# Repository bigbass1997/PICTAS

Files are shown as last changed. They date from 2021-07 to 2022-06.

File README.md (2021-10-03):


### Description
The PICTAS is an input device used to replay Tool-Assisted-Speedruns (aka Tool-Assisted-Superruns) on physical hardware.

A PIC18F47K42 microcontroller is used for the replay portion of the device, and the smaller PIC18F27K42 is used for controlling the input displays.

Unlike a typical TAS replay device, this one stores the TAS inputs on-board, using serial flash memory (W25Q128JVSIQ), capable of storing 16 MB of input data. The advantage is that USB communication is not required during replay. It simplifies the replay process, and greatly reduces the chance of corrupted inputs. Additionally, once programmed, the device can be used without a USB host computer (WIP feature).

This project is still a prototype under heavy development. While I will offer help and support as best I can, please understand that significant code and design changes can occur at any time.

### Usage
The general process looks like this: Load movie into a [host interface](https://github.com/bigbass1997/pictas-interface-rs). Program the movie's inputs and config options onto the PICTAS device. Finally, use one of the available start methods to begin the playback.

Refer to the [PICTAS-Interface project](https://github.com/bigbass1997/pictas-interface-rs) for details on how to use that software. Anyone is free to make their own interface software. There will be docs provided here once the communication protocol has stablized. The PICTAS communicates over USB at a 500,000 baud rate. Single byte commands are initiated from the interface. The PICTAS will respond with one or more bytes.

Because the input data is saved onto the device, you will _not_ need to reprogram it again unless you wish to change the TAS inputs or other configuration data.

### Flash Memory Map
```
0x000000 - 0xFFEFFF | Sequential controller inputs
0xFFF000 - 0xFFF0FF | Config options
0xFFF100 - 0xFFFFFF | Frame-numbered commands
```
All except the last sector (4KB) of memory, is dedicated to storing the TAS inputs. Format will depend on the console and how many controllers are used. Within the last sector, the first 256 bytes are for config options, while the rest is for special commands that are performed on specific frame numbers.

Each command is made up of a 3 byte wide number, which specifies the frame number. And then a 1 byte command.
```
0x00 | Console Reset
0x01 | Console Power off and on

0xFF | Null
```

### Input Displays
This replay device also supports input displays (aka viz/visualization boards), providing the viewers a way see which inputs are being pressed in real time.

The displays are designed to be placed on a SPI bus, where each display board shares the same clock and serial signals. Each device uses it's own Chip Select signal as a data latch.

An auxilary power supply must be connected for these displays. The PCB design is rated for a maximum of 2Amps.

### Discord/Support
If you have questions or suggestions, you can find me on the [N64brew Discord server](https://discord.gg/WqFgNWf) or the [TASBot server](https://discord.tas.bot/).

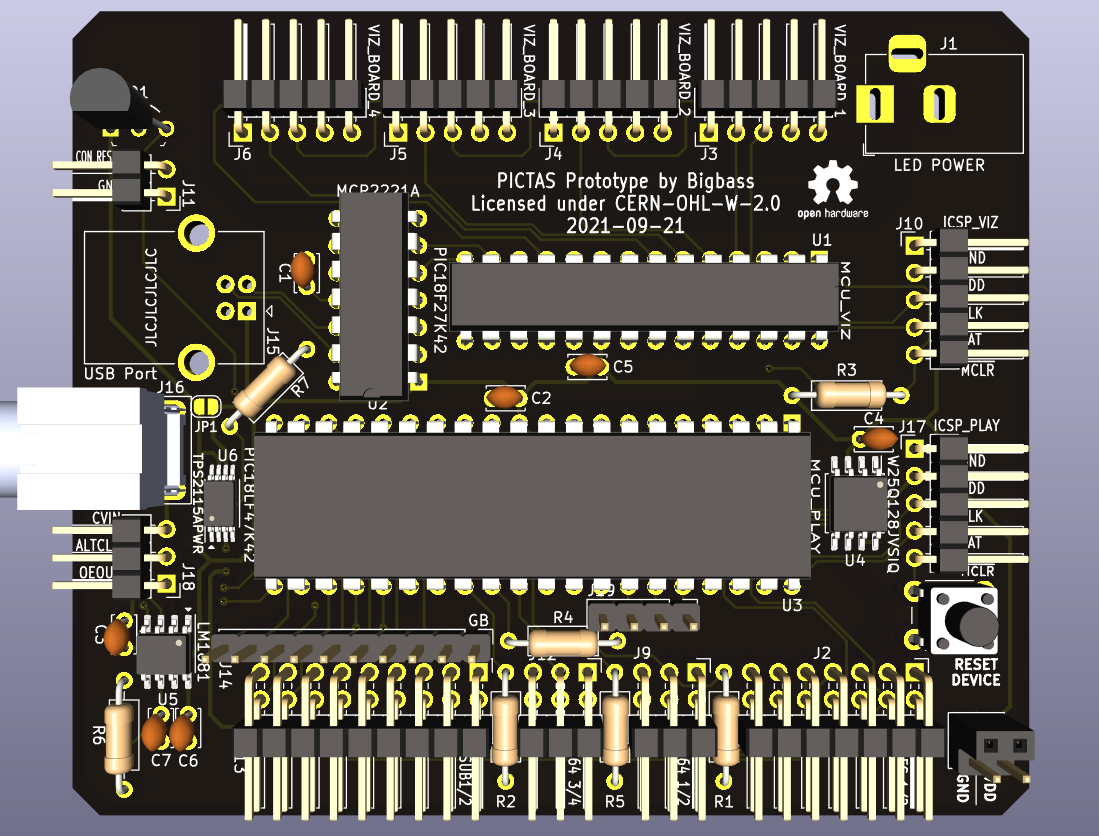
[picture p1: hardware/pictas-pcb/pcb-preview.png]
pcb design


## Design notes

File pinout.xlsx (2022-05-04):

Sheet: MCU-Play
Notes | I/O | Usage | Name | Pin |  | Pin | Name | Usage | I/O | Notes | Color Scheme
 | O | VPP/MCLR | RE3 | 1 | PIC18F47K42 | 40 | RB7 | ICSPDAT | I |  | PORTA
 | I/O | GEN/A2600/NES_LATCH | RA0 | 2 |  | 39 | RB6 | ICSPCLK | I |  | PORTB
 | I/O | GEN/A2600/NES_CLK1 | RA1 | 3 |  | 38 | RB5 | U1TX | O | UART1 TX | PORTC
 | O | GEN/A2600/NES_DATA1 | RA2 | 4 |  | 37 | RB4 | U1RX | I | UART1 RX | PORTD
 | I/O | GEN/A2600/NES_CLK2 | RA3 | 5 |  | 36 | RB3 | SPI1SDO | O | SDO | PORTE
 | O | GEN/A2600/NES_DATA2 | RA4 | 6 |  | 35 | RB2 | SPI1SCK | O | CLK | ICSP
 | O | GEN/A2600 | RA5 | 7 |  | 34 | RB1 | FLASH_CS | O | Flash Select
 |  |  | RE0 | 8 |  | 33 | RB0 | SPI1SDOI | I | SDI
 |  |  | RE1 | 9 |  | 32 | VDD
Write to Host | O | UART_HOST | RE2 | 10 |  | 31 | VSS
 |  |  | VDD | 11 |  | 30 | RD7 | N64_DATA4 | I/O
 |  |  | VSS | 12 |  | 29 | RD6 | N64_DATA3 | I/O
Alternative CLK | I | ALT_CLK | RA7 | 13 |  | 28 | RD5 | N64_DATA2 | I/O
 | O | GEN/A2600 | RA6 | 14 |  | 27 | RD4 | N64_DATA1 | I/O
 | O | GB/GEN/A2600 | RC0 | 15 |  | 26 | RC7 | GB | O
 | O | GB/GEN/A2600 | RC1 | 16 |  | 25 | RC6 | GB/GEN/A2600 | O
 | O | GB/GEN/A2600 | RC2 | 17 |  | 24 | RC5 | GB/GEN/A2600 | O
 | O | GB/GEN/A2600 | RC3 | 18 |  | 23 | RC4 | GB/GEN/A2600 | O
 |  |  | RD0 | 19 |  | 22 | RD3
Reset Console | O | CON_RESET | RD1 | 20 |  | 21 | RD2 | OEOUT | I | Odd/Even Field

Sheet: MCU-Viz
Notes | I/O | Usage | Name | Pin |  | Pin | Name | Usage | I/O | Notes | Color Scheme
 | O | VPP/MCLR | RE3 | 1 | PIC18F27K42 | 28 | RB7 | ICSPDAT | O |  | PORTA
 |  |  | RA0 | 2 |  | 27 | RB6 | ICSPCLK | O |  | PORTB
 |  |  | RA1 | 3 |  | 26 | RB5 | U2RX | I | UART-->MCU_PLAY | PORTC
 | O | STROBE1 | RA2 | 4 |  | 25 | RB4 | U2TX | O | UART<--MCU_PLAY | ICSP
 | O | STROBE2 | RA3 | 5 |  | 24 | RB3 | UART_HOST | I | Write to Host
 | O | STROBE3 | RA4 | 6 |  | 23 | RB2
 | O | STROBE4 | RA5 | 7 |  | 22 | RB1
 |  |  | VSS | 8 |  | 21 | RB0
 |  |  | RA7 | 9 |  | 20 | VDD
 |  |  | RA6 | 10 |  | 19 | VSS
SER | O | SPI1SDO | RC0 | 11 |  | 18 | RC7
CLK | O | SPI1SCK | RC1 | 12 |  | 17 | RC6
USB-->UART | I | U1RX | RC2 | 13 |  | 16 | RC5
USB<--UART | O | U1TX | RC3 | 14 |  | 15 | RC4

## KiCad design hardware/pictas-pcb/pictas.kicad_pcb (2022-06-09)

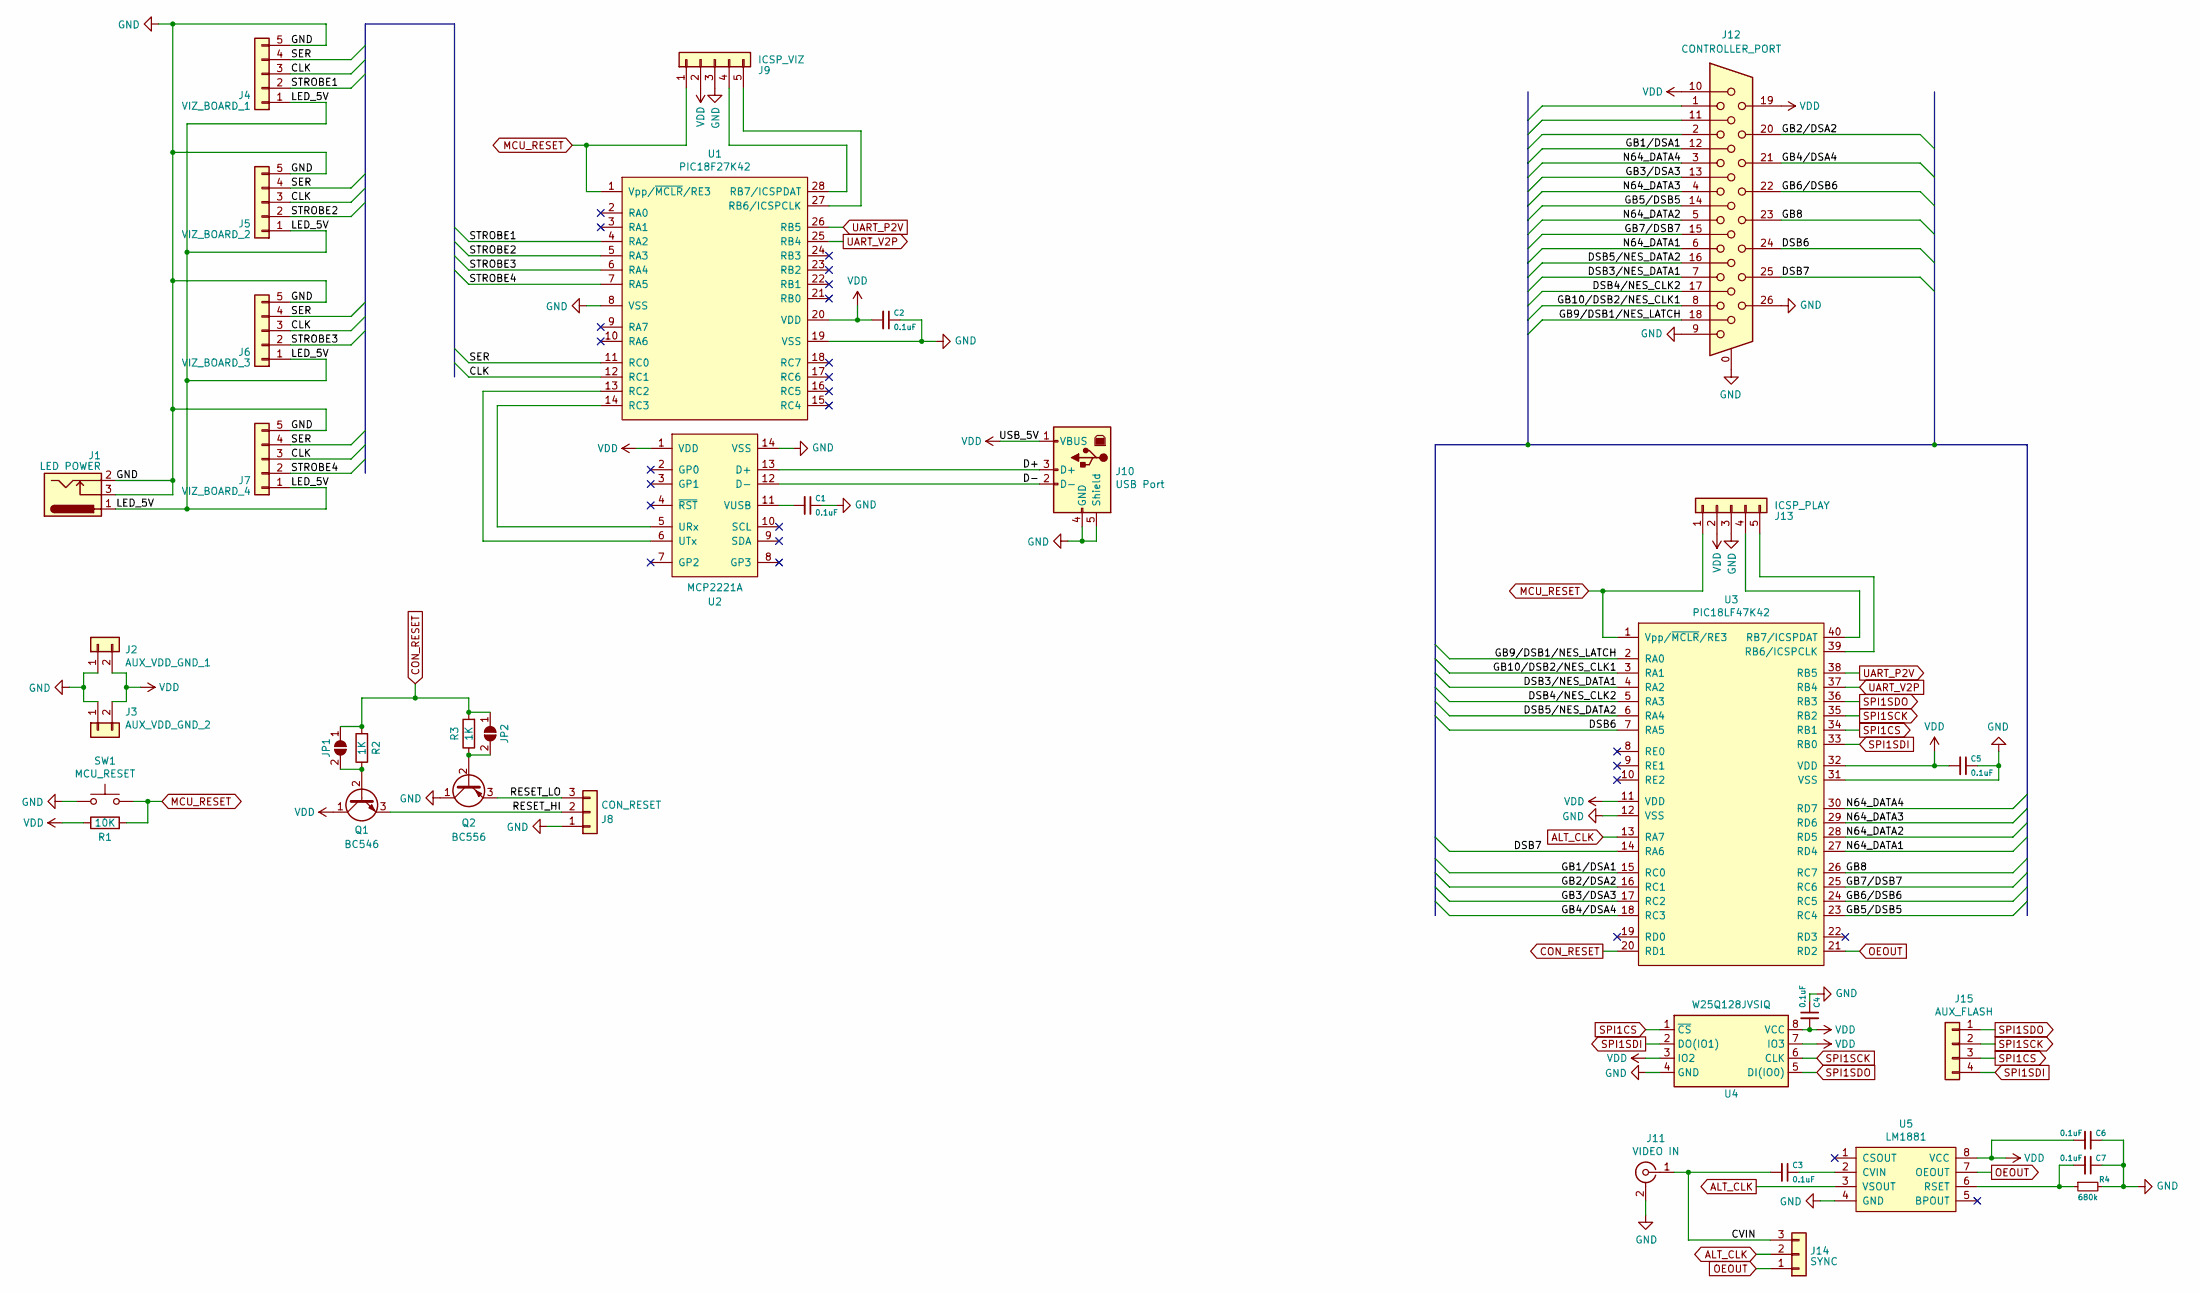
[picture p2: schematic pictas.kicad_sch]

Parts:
C1, C2, C3, C4, C5, C6, C7: 0.1uF; C_Disc_D3.4mm_W2.1mm_P2.50mm
J1: LED POWER; BarrelJack_Horizontal
J2: AUX_VDD_GND_1; PinHeader_1x02_P2.54mm_Vertical
J3: AUX_VDD_GND_2; PinSocket_1x02_P2.54mm_Vertical
J4: VIZ_BOARD_1; PinHeader_1x05_P2.54mm_Horizontal
J5: VIZ_BOARD_2; PinHeader_1x05_P2.54mm_Horizontal
J6: VIZ_BOARD_3; PinHeader_1x05_P2.54mm_Horizontal
J7: VIZ_BOARD_4; PinHeader_1x05_P2.54mm_Horizontal
J8: CON_RESET; PinHeader_1x03_P2.54mm_Horizontal
J9: ICSP_VIZ; PinSocket_1x05_P2.54mm_Horizontal
J10: USB Port; USB_B_OST_USB-B1HSxx_Horizontal
J11: VIDEO IN; PJRAN1X1U04X
J12: CONTROLLER_PORT; L77HDA26SD1CH4R
J13: ICSP_PLAY; PinSocket_1x05_P2.54mm_Horizontal
J14: SYNC; PinHeader_1x03_P2.54mm_Horizontal
J15: AUX_FLASH; PinHeader_1x04_P2.54mm_Vertical
JP1, JP2: SolderJumper_2_Open; SolderJumper-2_P1.3mm_Open_TrianglePad1.0x1.5mm
Q1: BC546; TO-92_Inline
Q2: BC556; TO-92_Inline
R1: 10K; R_Axial_DIN0207_L6.3mm_D2.5mm_P10.16mm_Horizontal
R2, R3: 1K; R_Axial_DIN0207_L6.3mm_D2.5mm_P10.16mm_Horizontal
R4: 680k; R_Axial_DIN0207_L6.3mm_D2.5mm_P10.16mm_Horizontal
SW1: MCU_RESET; SW_PUSH_6mm_H7.3mm
U1: PIC18F27K42; DIP-28_W7.62mm
U2: MCP2221A; DIP-14_W7.62mm
U3: PIC18LF47K42; DIP-40_W15.24mm
U4: W25Q128JVSIQ; SOIC-8_5.275x5.275mm_P1.27mm
U5: LM1881; SOIC-8_3.9x4.9mm_P1.27mm

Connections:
/CLK: J4.3, J5.3, J6.3, J7.3, U1.12 (RC1)
/CVIN: C3.2, J11.1 (In), J14.3
/D+: J10.3 (D+), U2.13 (D+)
/D-: J10.2 (D-), U2.12 (D-)
/DSB3/NES_DATA1: J12.7, U3.4 (RA2)
/DSB4/NES_CLK2: J12.17, U3.5 (RA3)
/DSB5/NES_DATA2: J12.16, U3.6 (RA4)
/DSB6: J12.24, U3.7 (RA5)
/DSB7: J12.25, U3.14 (RA6)
/GB1/DSA1: J12.12, U3.15 (RC0)
/GB2/DSA2: J12.20, U3.16 (RC1)
/GB3/DSA3: J12.13, U3.17 (RC2)
/GB4/DSA4: J12.21, U3.18 (RC3)
/GB5/DSB5: J12.14, U3.23 (RC4)
/GB6/DSB6: J12.22, U3.24 (RC5)
/GB7/DSB7: J12.15, U3.25 (RC6)
/GB8: J12.23, U3.26 (RC7)
/GB9/DSB1/NES_LATCH: J12.18, U3.2 (RA0)
/GB10/DSB2/NES_CLK1: J12.8, U3.3 (RA1)
/LED_5V: J1.1, J4.1, J5.1, J6.1, J7.1
/N64_DATA1: J12.6, U3.27 (RD4)
/N64_DATA2: J12.5, U3.28 (RD5)
/N64_DATA3: J12.4, U3.29 (RD6)
/N64_DATA4: J12.3, U3.30 (RD7)
/RESET_HI: J8.2, Q1.3 (E)
/RESET_LO: J8.3, Q2.3 (E)
/SER: J4.4, J5.4, J6.4, J7.4, U1.11 (RC0)
/STROBE1: J4.2, U1.4 (RA2)
/STROBE2: J5.2, U1.5 (RA3)
/STROBE3: J6.2, U1.6 (RA4)
/STROBE4: J7.2, U1.7 (RA5)
ALT_CLK: J14.2, U3.13 (RA7), U5.3 (VSOUT)
CON_RESET: JP1.1 (A), JP2.1 (A), R2.2, R3.2, U3.20 (RD1)
GND: C1.1, C2.1, C4.1, C5.1, C6.1, C7.1, J1.2, J1.3, J2.1, J3.1, J4.5, J5.5, J6.5, J7.5, J8.1, J9.3, J10.4 (GND), J10.5 (Shield), J11.2 (Ext), J12.0, J12.9, J12.26, J13.3, Q2.1 (C), R4.2, SW1.1, U1.8 (VSS), U1.19 (VSS), U2.14 (VSS), U3.12 (VSS), U3.31 (VSS), U4.4 (GND), U5.4 (GND)
MCU_RESET: J9.1, J13.1, R1.2, SW1.2, U1.1 (Vpp/~MCLR/RE3), U3.1 (Vpp/~MCLR/RE3)
unnamed: C1.2, U2.11 (VUSB)
unnamed: C3.1, U5.2 (CVIN)
unnamed: C7.2, R4.1, U5.6 (RSET)
unnamed: J9.4, U1.28 (RB7/ICSPDAT)
unnamed: J9.5, U1.27 (RB6/ICSPCLK)
unnamed: J13.4, U3.40 (RB7/ICSPDAT)
unnamed: J13.5, U3.39 (RB6/ICSPCLK)
unnamed: JP1.2 (B), Q1.2 (B), R2.1
unnamed: JP2.2 (B), Q2.2 (B), R3.1
unnamed: U1.13 (RC2), U2.6 (UTx)
unnamed: U1.14 (RC3), U2.5 (URx)
OEOUT: J14.1, U3.21 (RD2), U5.7 (OEOUT)
SPI1CS: J15.3, U3.34 (RB1), U4.1 (~CS)
SPI1SCK: J15.2, U3.35 (RB2), U4.6 (CLK)
SPI1SDI: J15.4, U3.33 (RB0), U4.2 (DO(IO1))
SPI1SDO: J15.1, U3.36 (RB3), U4.5 (DI(IO0))
UART_P2V: U1.26 (RB5), U3.38 (RB5)
UART_V2P: U1.25 (RB4), U3.37 (RB4)
VDD: C2.2, C4.2, C5.2, C6.2, J2.2, J3.2, J9.2, J10.1 (VBUS), J12.10, J12.19, J13.2, Q1.1 (C), R1.1, U1.20 (VDD), U2.1 (VDD), U3.11 (VDD), U3.32 (VDD), U4.3 (IO2), U4.7 (IO3), U4.8 (VCC), U5.8 (VCC)

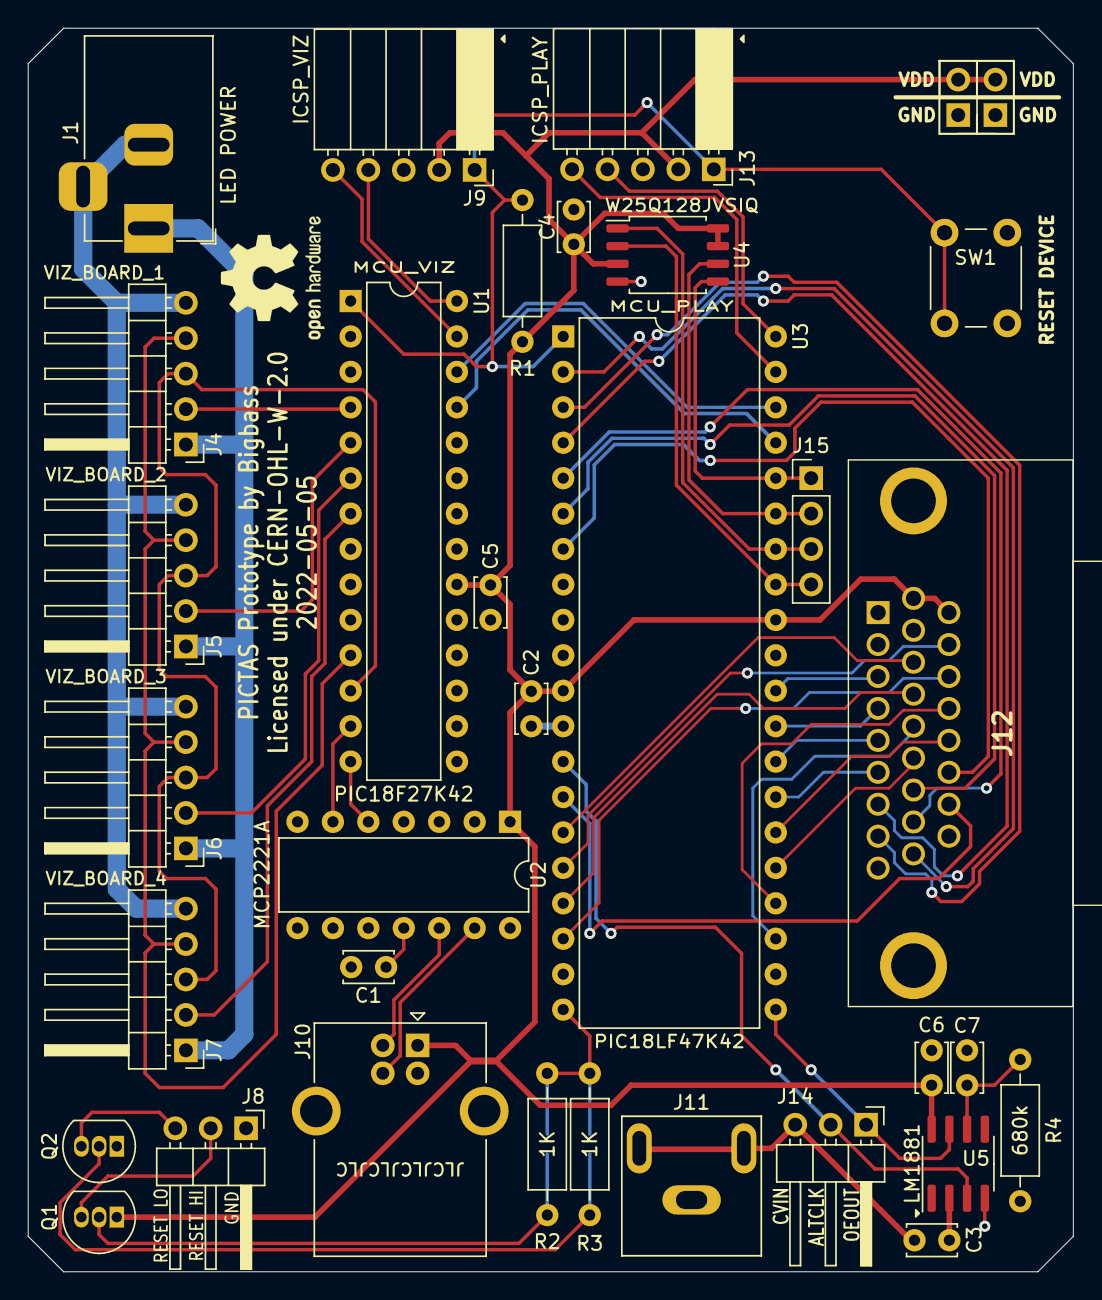
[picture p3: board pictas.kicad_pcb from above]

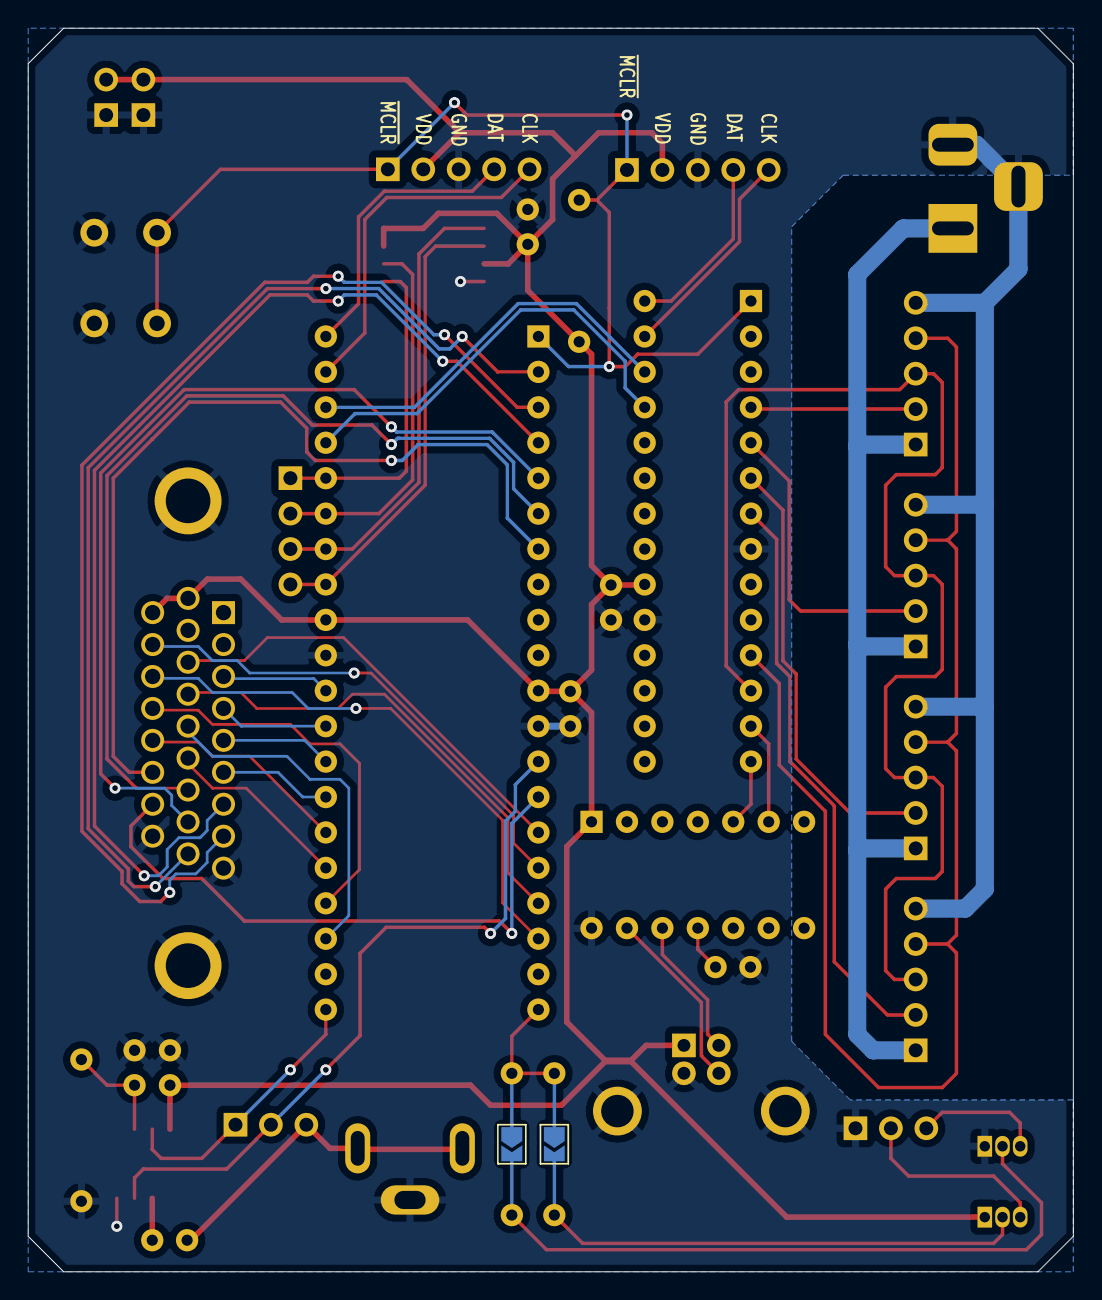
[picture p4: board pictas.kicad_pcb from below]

Board: 2 copper layers, 74.9 x 89.2 mm, 36 parts (2 on the bottom side), 54 nets.

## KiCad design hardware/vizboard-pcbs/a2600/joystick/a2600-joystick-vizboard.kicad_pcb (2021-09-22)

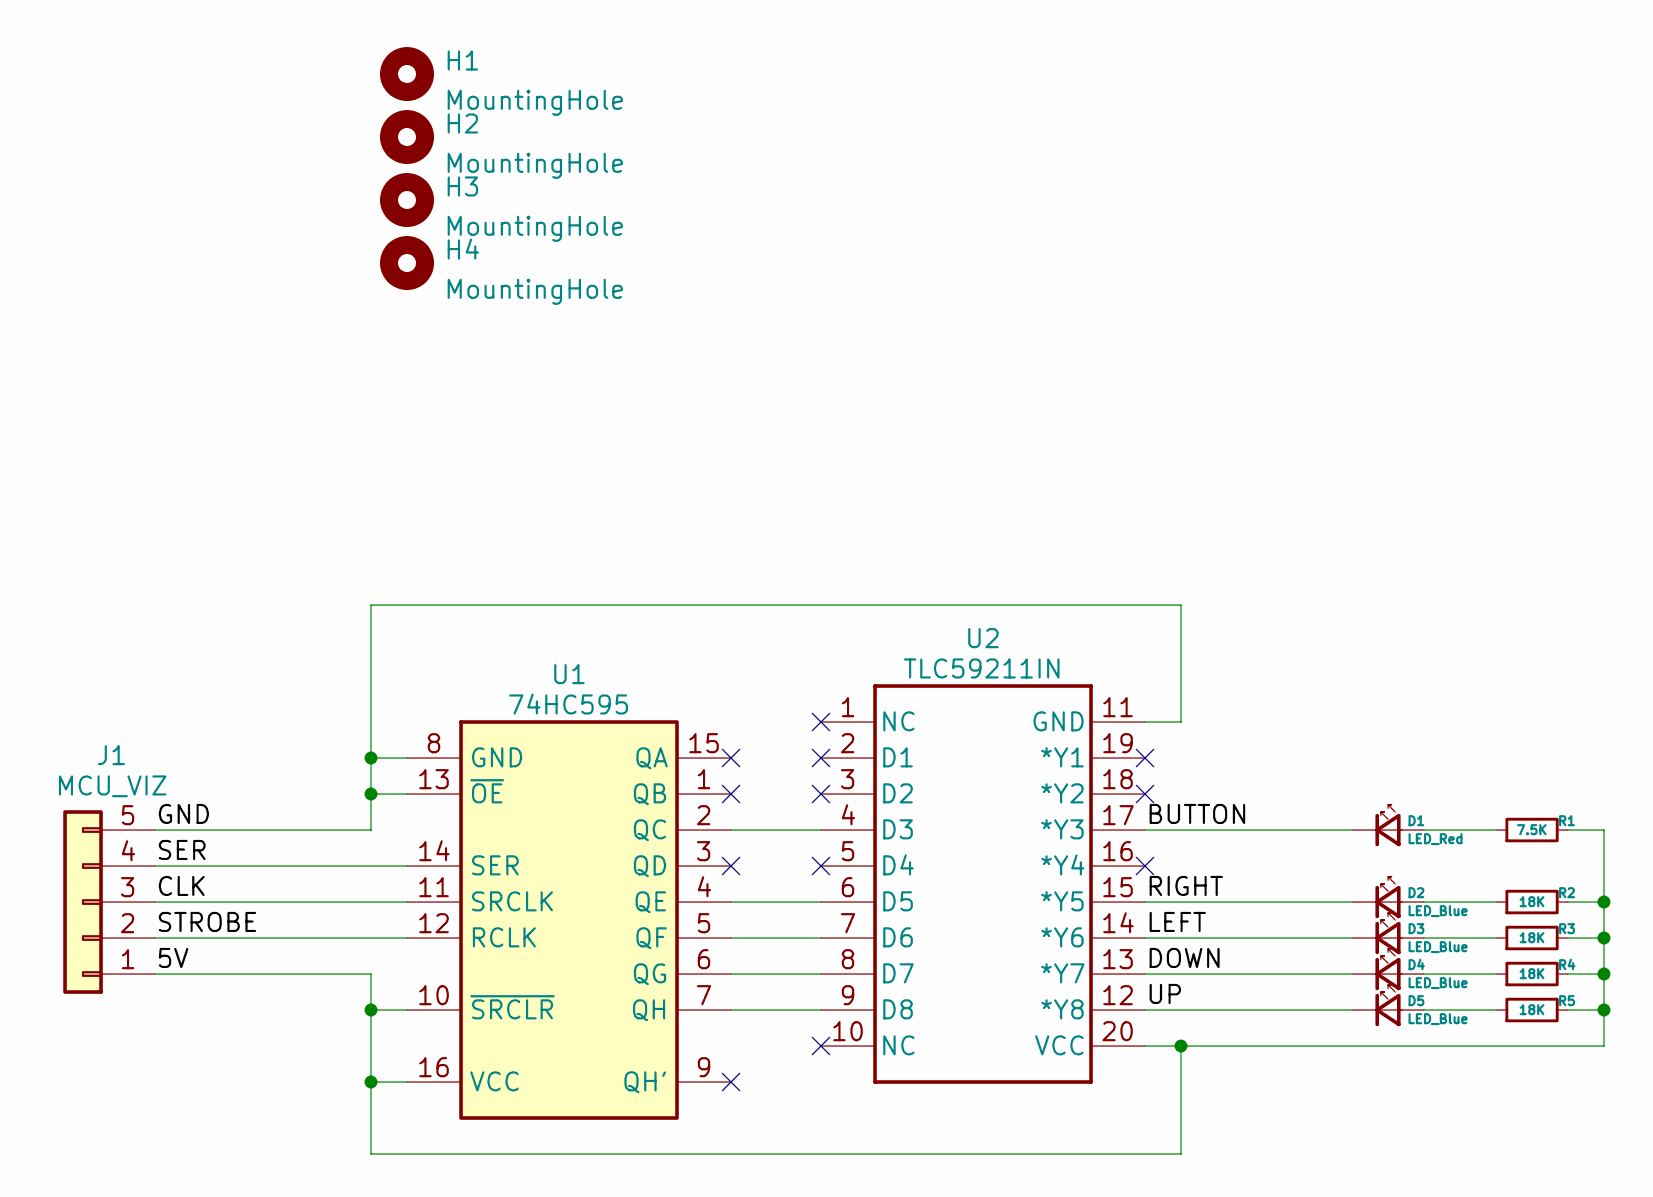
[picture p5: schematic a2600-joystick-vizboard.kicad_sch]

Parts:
D1: LED_Red; LED_D5.0mm
D2, D3, D4, D5: LED_Blue; LED_D5.0mm
H1, H2, H3, H4: MountingHole; MountingHole_3.2mm_M3
J1: MCU_VIZ; PinHeader_1x05_P2.54mm_Horizontal
R1: 7.5K; R_Axial_DIN0207_L6.3mm_D2.5mm_P10.16mm_Horizontal
R2, R3, R4, R5: 18K; R_Axial_DIN0207_L6.3mm_D2.5mm_P10.16mm_Horizontal
U1: 74HC595; DIP-16_W7.62mm
U2: TLC59211IN; DIP-20_W7.62mm

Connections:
/5V: J1.1, R1.2, R2.2, R3.2, R4.2, R5.2, U1.10 (~SRCLR), U1.16 (VCC), U2.20 (VCC)
/BUTTON: D1.1 (K), U2.17 (*Y3)
/CLK: J1.3, U1.11 (SRCLK)
/DOWN: D4.1 (K), U2.13 (*Y7)
/GND: J1.5, U1.8 (GND), U1.13 (~OE), U2.11 (GND)
/LEFT: D3.1 (K), U2.14 (*Y6)
/RIGHT: D2.1 (K), U2.15 (*Y5)
/SER: J1.4, U1.14 (SER)
/STROBE: J1.2, U1.12 (RCLK)
/UP: D5.1 (K), U2.12 (*Y8)
unnamed: D1.2 (A), R1.1
unnamed: D2.2 (A), R2.1
unnamed: D3.2 (A), R3.1
unnamed: D4.2 (A), R4.1
unnamed: D5.2 (A), R5.1
unnamed: U1.2 (QC), U2.4 (D3)
unnamed: U1.4 (QE), U2.6 (D5)
unnamed: U1.5 (QF), U2.7 (D6)
unnamed: U1.6 (QG), U2.8 (D7)
unnamed: U1.7 (QH), U2.9 (D8)

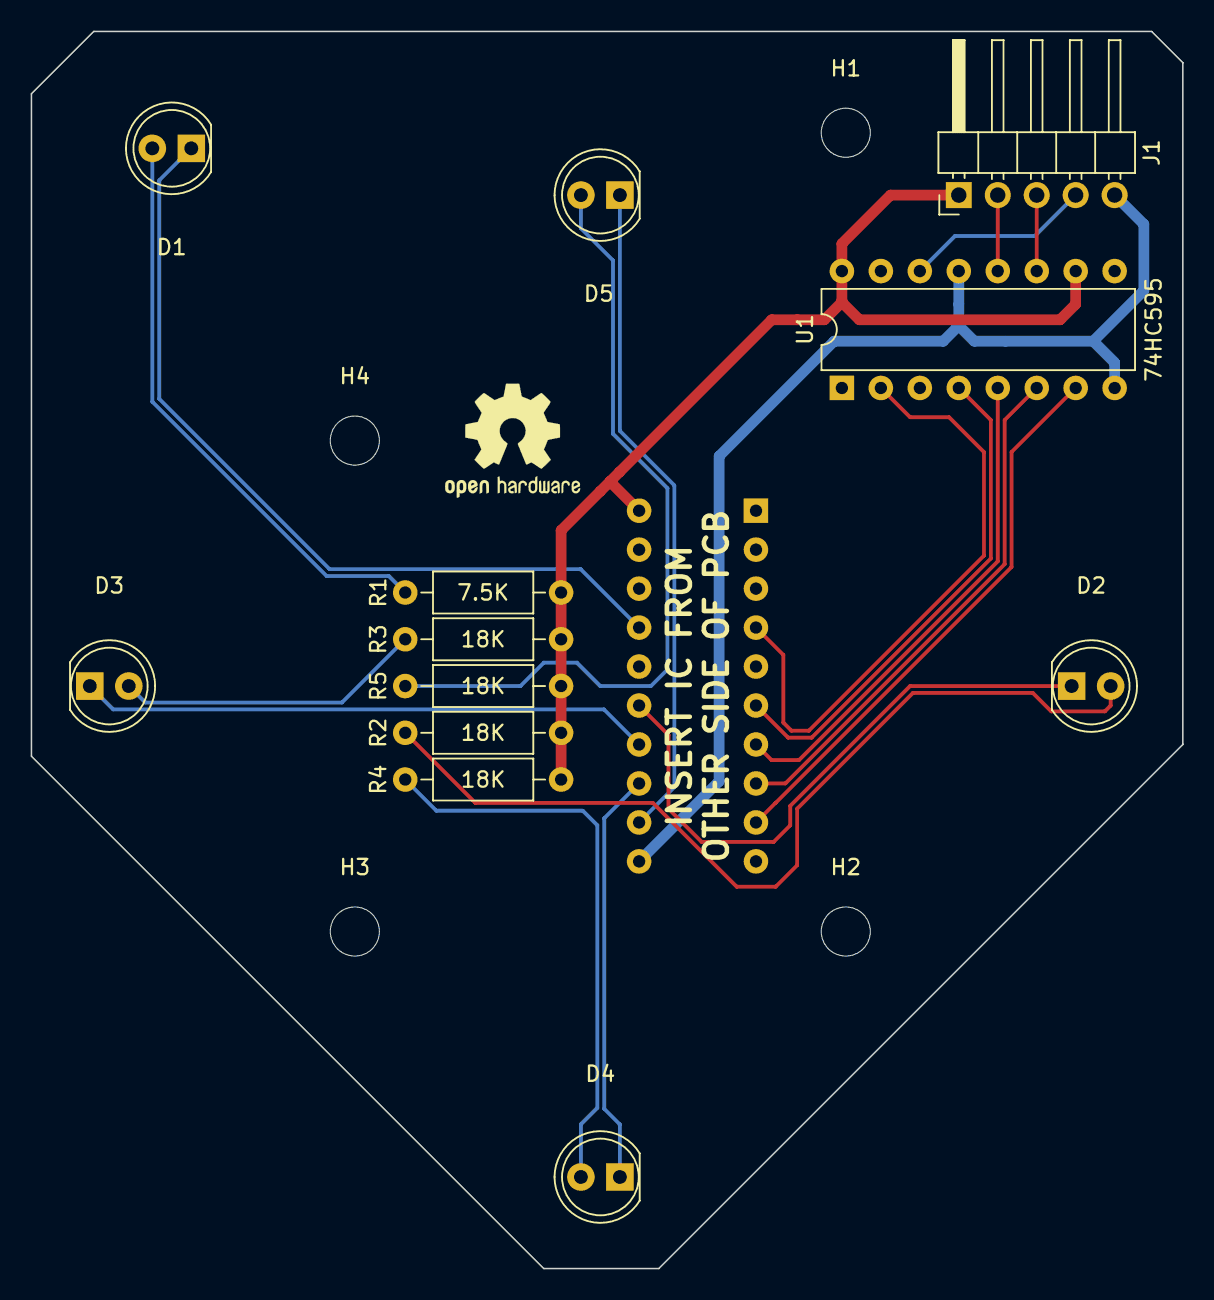
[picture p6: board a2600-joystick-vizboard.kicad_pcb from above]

Board: 2 copper layers, 75.1 x 80.6 mm, 17 parts (1 on the bottom side), 20 nets.

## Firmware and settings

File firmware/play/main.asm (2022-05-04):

    include "p18f47k42.inc"
    include "macros.inc"
    processor 18f47k42
    
    CONFIG WDTE = OFF
   ; CONFIG DEBUG = ON
    CONFIG LVP = ON
    CONFIG MCLRE = EXTMCLR
    CONFIG MVECEN = ON ; Eanbles Interrupt Vector Table ; IVTBASE + 2*(vector number)
    
    CONFIG RSTOSC = HFINTOSC_64MHZ
    CONFIG FEXTOSC = OFF
    CONFIG CLKOUTEN = OFF
    
    CONFIG XINST = ON
    
ResVec      code	0x0000
    goto    Setup
    
IOCVec	    code	0x0016	; (0x0008 + (2 * 7))
    dw	    (0x0100>>2)
    
INT0Vec	    code	0x0018	; (0x0008 + (2 * 8))
    dw	    (0x0300>>2)
    
TMR0Vec	    code	0x0046	; (0x0008 + (2 * 31))
    dw	    (0x0500>>2)
    
U1RXVec	    code	0x003E	; (0x0008 + (2 * 27))
    dw	    (0x0600>>2)
    
	    code	0x1000
; === Look at bottom of file for ISR routines ===
    
; === DEFINE PINS (text substitutions) ===
; refer to pinout documentation for more information
; reminder: all button input pins should be pulled-DOWN (default state is cleared aka 0)
;           connect pin to power to set button to a "pressed" state
#define	    PIN_NES_DATA2	LATA,  4
#define	    PIN_NES_CLK2	PORTA, 3

#define	    PIN_NES_DATA1	LATA,  2
#define	    PIN_NES_CLK1	PORTA, 1

#define	    PIN_NES_LATCH	PORTA, 0    ; Latch pins for each controller are connected at console-level

#define     PIN_FLASH_CS        LATB,  1
#define	    PIN_FLASH_CS_RD	PORTB, 1    ; Used to check what the last set state was

#define	    PIN_UART_HOST	LATE,  2    ; Signal to MCU_Viz whether to write UART to host or not

#define     PIN_N64_DATAIN      PORTD, 4
#define     PIN_N64_DATAOUT     LATD,  4    ; LAT register is used for writing data out
#define     TRIS_N64_DATA       TRISD, 4

#define	    PIN_STAT_LED	LATD,  0    ; Status LED indicator
#define	    PIN_CON_RESET	LATD,  1


; === REGISTERS ===
; ACCESS BANK  (0x00 - 0x5F)
ZEROS_REG       equ H'00' ; Always 0x00
ONES_REG        equ H'01' ; Always 0xFF

N64_BIT_REG     equ H'02' ; This register is used to temporarily store 3-4us of data
                          ; to determine if the data recieved is a 0 or 1 or a stop bit.
N64_CMD_REG     equ H'03'

; 0x04 - 0x07 unused

N64_STATE_REG1  equ H'08' ; Buffer:  Button states
N64_STATE_REG2  equ H'09' ; Buffer:  Button states
N64_STATE_REG3  equ H'0A' ; Buffer:  Analog Stick X-Axis ; -127 to +128
N64_STATE_REG4  equ H'0B' ; Buffer:  Analog Stick Y-Axis ; -127 to +128

TX_DATA         equ H'0C' ; Alias for TX_DATA1
TX_DATA1        equ H'0C' ; Data to be transmitted to the console
TX_DATA2        equ H'0D' ; Data to be transmitted to the console, used as "double buffer"

UTIL_FLAGS      equ H'0E' ; Utility Flags, initalized with 0x00
; <7> If set, determined byte is invalid, decoding should halt
; <6> If set, no new NES latches should be accepted
; <5> If set, a TAS replay is in progress
; <4> Used by FlashLoadNextEvent to store previous PIN_FLASH_CS state
; <3> If set, reset NES on next latch
; <2> If set, A2600/Gen vsync has occured; is cleared once A2600/Gen loop has acknowledge this
; <1:0> Unused

; Pause Clock
PAUSE_REG_0     equ H'10'
PAUSE_REG_1     equ H'11'
PAUSE_REG_2     equ H'12'

PAUSE_TMP_0     equ H'13'
PAUSE_TMP_1     equ H'14'
PAUSE_TMP_2     equ H'15'

; Auxillary Loop Counters
LOOP_COUNT_0    equ H'16'
LOOP_COUNT_1    equ H'17'

; FLASH Pointers
FLASH_ADDR_HIGH equ H'18'
FLASH_ADDR_MID  equ H'19'
FLASH_ADDR_LOW  equ H'1A'

FLASH_LAST_HIGH	equ H'1B'
FLASH_LAST_MID	equ H'1C'
FLASH_LAST_LOW	equ H'1D'

FLASH_EVENT_MID equ H'1E'
FLASH_EVENT_LOW equ H'1F'

; NES Controller Data
NES_STATE_REG1	equ H'20'
NES_STATE_REG2	equ H'21'
NES_STATE_TMP1	equ H'22'
NES_STATE_TMP2	equ H'23'

; InterUART Protocol Constants
MCUCMD_HOST	equ H'24'   ; init to 0x01
MCUCMD_SHOW8_0	equ H'25'   ; init to 0xD0
MCUCMD_SHOW8_1	equ H'26'   ; init to 0xD1
MCUCMD_SHOW8_2	equ H'27'   ; init to 0xD2
MCUCMD_SHOW8_3	equ H'28'   ; init to 0xD3

; A2600 Frame State Data
A2600_STATE_REG1    equ	H'29'
A2600_STATE_REG2    equ H'2A'
A2600_STATE_REG3    equ H'2B'

GEN_STATE_REG1	equ H'2C'
GEN_STATE_REG2	equ H'2D'

; 0x2E - 0x56 unused

LAST_USB_BYTE	equ H'57'

CFG_EVENT_HIGH	equ H'58'
CFG_EVENT_MID	equ H'59'
CFG_EVENT_LOW	equ H'5A'
CFG_EVENT_CMD	equ H'5B'

CUR_INPUT_HIGH	equ H'5C'
CUR_INPUT_MID	equ H'5D'
CUR_INPUT_LOW	equ H'5E'   ; keeps track of the current input frame

JUNK_REG        equ H'5F'

; BANK 0  (0x60 - 0xFF)
; These bytes are used for temporary storage of data coming from or going to the N64 console.
; While only 4 addresses are defined, this whole section of memory is dedicated for this purpose.
; Remember to specify in every instruction to use the BSR instead of Access memory.
N64_DATA_DETER  equ H'60'
N64_DATA_TMP0   equ H'61'
N64_DATA_TMP1   equ H'62'
N64_DATA_TMP2   equ H'63'
N64_DATA_TMP3   equ H'64'

; BANK 1
; This bank is used when writing a 256 byte sector of data to the FLASH memory

; BANK 2
; Config options are stored here

; 0x00 - 0xFC unused

CFG_LASTF_HIGH	equ H'FD'
CFG_LASTF_MID	equ H'FE'
CFG_LASTF_LOW	equ H'FF'



; === CONSTANT BYTES ===
USB_CMD_PING        equ H'01'
USB_CMD_DUMP        equ H'02'
USB_CMD_RUN_N64     equ H'03'
USB_CMD_RUN_NES     equ H'04'
USB_CMD_RUNED_NES   equ H'05'
USB_CMD_RUNRST_NES  equ H'06'
USB_CMD_RUNMAN_NES  equ H'07'
USB_CMD_RUN_A2600   equ H'08'
USB_CMD_RUN_GEN	    equ H'09'
USB_CMD_PROGTAS     equ H'AA'
USB_CMD_PROGCFG     equ H'AB'
USB_CMD_RESETMCU    equ H'AE'

N64_CMD_RESET       equ H'FF'
N64_CMD_INFO        equ H'00'
N64_CMD_STATE       equ H'01'
N64_CMD_READACCES   equ H'02' ; unimplemented
N64_CMD_WRITEACCES  equ H'03' ; unimplemented

; https://n64brew.dev/wiki/Joybus_Protocol
N64_BIT_ZERO    equ B'11110001'
N64_BIT_ONE     equ B'11110111'
N64_BIT_CONSSTP equ B'11110111' ; bit <0> is not technically used, but for ease of programming, it is set to 1
N64_BIT_CONTSTP equ B'11110011'

; COMMON SUBROUTINES (may also contain macros) ;
    include "sub-utilities.inc"
    include "sub-flash.inc"
    
; Initialize device ;
Setup:
    include "setup.inc"
    
    movlb   B'000000'
    ;goto    GenesisMain ;;; DEBUG
    
;;;;;====================== Main Loop ======================;;;;;
MainLoop:
    
    goto    MainLoop
    
    
;;;;;====================== N64 Logic ======================;;;;;
    include "n64.inc"
    
    
;;;;;====================== NES Logic ======================;;;;;
    include "nes.inc"
    
    
;;;;;====================== A2600 Logic ======================;;;;;
    include "a2600.inc"
    
    
;;;;;====================== Genesis Logic ======================;;;;;
    include "genesis.inc"
    
    
    
; INTERRUPT SUBROUTINES ;
    
    include "isr.ioc.inc"
    include "isr.int0.inc"
    include "isr.tmr0.inc"
    include "isr.u1rx.inc"
    
    end

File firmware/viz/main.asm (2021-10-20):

    include "p18f27k42.inc"
    processor 18f27k42
    
    CONFIG WDTE = OFF
   ; CONFIG DEBUG = ON
    CONFIG LVP = ON
    CONFIG MCLRE = EXTMCLR
    CONFIG MVECEN = ON ; Eanbles Interrupt Vector Table ; IVTBASE + 2*(vector number)
    
    CONFIG RSTOSC = HFINTOSC_64MHZ
    
    CONFIG XINST = ON
    
ResVec      code	0x0000
    goto    Setup
    
U1RXVec	    code	0x003E	; (0x0008 + (2 * 27))
    dw	    (0x0200>>2)
    
U2RXVec	    code	0x006C	; (0x0008 + (2 * 50))
    dw	    (0x0400>>2)
    
	    code	0x0600
; === Look at bottom of file for ISR routines ===
    
; === DEFINE PINS (text substitutions) ===
; refer to pinout documentation for more information
; reminder: all button input pins should be pulled-DOWN (default state is cleared aka 0)
;           connect pin to power to set button to a "pressed" state
#define	    PIN_STROBE3		LATA,  5
#define	    PIN_STROBE2		LATA,  4
#define	    PIN_STROBE1		LATA,  3
#define	    PIN_STROBE0		LATA,  2

; === REGISTERS ===
; ACCESS BANK  (0x00 - 0x5F)
ZEROS_REG       equ H'00' ; Always 0x00
ONES_REG        equ H'01' ; Always 0xFF

UTIL_FLAGS      equ H'02' ; Utility Flags, initalized with 0x00
; <7:0> Unused

; Pause Clock
PAUSE_REG_0     equ H'03'
PAUSE_REG_1     equ H'04'
PAUSE_REG_2     equ H'05'

PAUSE_TMP_0     equ H'06'
PAUSE_TMP_1     equ H'07'
PAUSE_TMP_2     equ H'08'

; Auxillary Loop Counters
LOOP_COUNT_0    equ H'09'
LOOP_COUNT_1    equ H'0A'

; 0x0B - 0x5E unused

TEMP_REG        equ H'5F'

; BANK 0  (0x60 - 0xFF)
; Unused

; BANK 1
; MCU-Play FIFO Buffer
; Data received from MCU-Play will be stored here.
; FIFO is naive. It has a pointer and a size.
; If size > 255, it will wrap to zero. Buffer should never be this large though.


; === CONSTANT BYTES ===
MCUCMD_HOST	equ H'01'   ; Send the next byte to host

MCUCMD_SHOW8_BASE   equ H'D0'
MCUCMD_SHOW8_0	equ H'D0'   ; Send the next byte to SPI bus and strobe #0
MCUCMD_SHOW8_1	equ H'D1'   ; Send the next byte to SPI bus and strobe #1
MCUCMD_SHOW8_2	equ H'D2'   ; Send the next byte to SPI bus and strobe #2
MCUCMD_SHOW8_3	equ H'D3'   ; Send the next byte to SPI bus and strobe #3

; === SUBROUTINE & MACRO INCLUDES === ;
    include "macros.inc"
    include "sub-utilities.inc"

Setup:
    include "startup.inc"
    
    movlb   B'000000'
    
    ;; debug start ;;
    ;clrf    LOOP_COUNT_0
    ;setf    PAUSE_REG_0
;Debug_LoopSPI:
    ;movf    LOOP_COUNT_0, W
    ;call    WriteSPI_BUS0
    ;call    Pause2D
    
    ;incfsz  LOOP_COUNT_0
    ;goto    Debug_LoopSPI
    
    clrf    WREG
    call    WriteSPI_BUS0
    call    WriteSPI_BUS1
    call    WriteSPI_BUS2
    call    WriteSPI_BUS3
    ;; debug end ;;
    
    
;;;;;====================== MAIN LOOP ======================;;;;;
Start:
    include "cmd-buffer.inc"
    
    goto    Start
    
    
    
;;;;;================ INTERRUPT SUBROUTINES ================;;;;;
U1RXISR	    code	0x0200	; Byte recieved from USB  (high priority)
    BANKSEL PIR3
U1RXISR_Retry:
    movffl  U1RXB, U2TXB ; relay bytes to MCU_Play
    
    btfsc   PIR3, U1RXIF
    goto    U1RXISR_Retry
    
    retfie  1
    
U2RXISR	    code	0x0400	; Byte recieved from MCU_Play  (low priority)
    BANKSEL PIR6
U2RXISR_Retry:
    movffl  U2RXB, POSTINC0
    movlw   D'1'
    movwf   FSR0H
    
    btfsc   PIR6, U2RXIF
    goto    U2RXISR_Retry
    
    bsf	    SHADCON, SHADLO
    movffl  WREG_SHAD, WREG
    bcf	    SHADCON, SHADLO
    movlb   B'000000'
    retfie  0
    
    end

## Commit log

2020-12-18 SPI with FLASH tests working
    [pinout.xlsx]
2020-12-19 Added USB commands and communication. Program command is broken!
    [main.asm]
2020-12-20 More work on USB commands. Programming doesn't appear to be completely working for large datasets (static maybe?)
    [main.asm]
2021-01-18 Commented out debugging line that skipped USB communication. Added debug line to send back the byte just received over USB for validation.
    [main.asm]
2021-01-31 Changed line endings for new linux dev environment
    [pictas.sch]
2021-02-18 Added NES support, nothing verified yet though.
    [pinout.xlsx]
2021-02-18 Sped up SPI communication for NES. Confirmed TAS replay worked with this firmware.
2021-02-21 Implemented latch filtering aka windowing. Extra latches will repeat frame data for games were the first latch isn't the true input. Implemented clock filtering (additional 2us hardcoded atm). Added 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
2021-02-25 Fixed major bug where inputs within the same frame would not repeat more than one additional time, even if latches occurred more than that.
    [main.asm]
2021-03-06 Work in progress PCB design
    [pictas.sch, usb-interface.sch]
2021-03-09 Redesigned PCB. Better controller placement and added visualization board connectors.
    [pictas.kicad_pcb, pictas.sch, power-select.sch]
2021-03-25 Added external TAS start button and added LED indicator.
    [pinout.xlsx]
2021-04-03 Added code to support Everdrive start-ups, but it doesn't work quite as intended. Committing still as it provides framework, and still does allow starting from everdrive if the appropriate number of 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
    [main.asm]
2021-04-04 Added automatic NES reset capability
    [pinout.xlsx]
2021-04-21 Updated schematic and prototype PCB design.
    [pictas.kicad_pcb, pictas.sch, pinout.xlsx]
2021-04-22 Major overhaul to visual input display feature.
    [pictas.sch, pinout.xlsx]
2021-06-17 Added reprogrammable config space in FLASH and changed how console resets are handled.
    [main.asm]
2021-06-19 Fixed reset handling (previous commit was very broken)
    [main.asm]
2021-06-20 Fixed timing bug where the MCU was operating too low after the latch pulse.
    [main.asm]
2021-06-27 Reworked when inputs are loaded from flash, and changed latch/clock response behavior to properly handle overreads and latches without all 8 clocks.
    [main.asm]
2021-07-12 Added NES vizboard input display. Reorganized hardware directories. Changed license to the more suitable CERN OHL-W
    [pictas.kicad_pcb, pictas.sch, pinout.xlsx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]
2021-07-16 Revised PCB design again.
    [pictas-B_Cu.gbl, pictas-B_Mask.gbs, pictas-B_Paste.gbp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]
2021-07-18 Fixed firmware bug where the device was wrongly initializing the TAS at boot, instead of at start of playback.
    [main.asm]
2021-08-01 Partially working. SPI to FLASH has severe issues on PCB
    [pictas.kicad_pcb, pictas.sch, pinout.xlsx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]
2021-09-01 More redesign progress
    [pictas.kicad_pcb, pictas.sch]
2021-09-19 More design changes
    [pictas.kicad_pcb, pictas.sch]
2021-09-21 New firmware confirmed to be able to program FLASH and verified using mass dump.
    [pinout.xlsx]
2021-09-21 Finalized new prototype designs.
    [pictas-B_Cu.gbl, pictas-B_Mask.gbs, pictas-B_Paste.gbp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]
2021-09-22 Added A2600 Joystick input display pcb.
    [a2600-joystick-vizboard-B_Cu.gbl, a2600-joystick-vizboard-B_Mask.gbs, a2600-joystick-vizboard-B_Paste.gbp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]
2021-10-03 Version update and minor joystick board changes.
2021-10-03 Reorganized pcb files
2021-10-03 Fixed strobe pinout to match hardware, and now clears all input displays at startup.
    [main.asm]
2021-10-03 Fixed inter-board communication bug (TRISE[2] set incorrectly on MCU-Play)
2021-10-04 Updated pinout spreadsheet to reflect current design.
    [pinout.xlsx]
2021-10-20 Added new inter-MCU communication protocol with QoL firmware changes.
    [pictas.kicad_sch, power-select.kicad_sch]
2021-10-20 Added reset command (can be used to stop a replay)
    [main.asm]
2022-05-04 Atari 2600 and beginner Genesis work; reorganized firmware.
    [pictas.kicad_pcb, pictas.kicad_sch, pinout.xlsx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]
2022-06-09 Progress toward replacing pinheaders with D-Sub connector.
    [pictas.kicad_pcb, pictas.kicad_sch]

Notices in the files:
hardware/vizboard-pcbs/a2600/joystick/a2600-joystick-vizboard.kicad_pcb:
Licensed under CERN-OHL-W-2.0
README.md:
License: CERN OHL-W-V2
